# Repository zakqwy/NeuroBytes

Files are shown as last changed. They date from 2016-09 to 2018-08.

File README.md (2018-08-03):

## NOTE
This repository is no longer actively maintained or current. This clean break helped us do many things, such as:
- switch microcontroller platforms from ATtiny88 (8-bit AVR) to STM32L0s (ARM Cortex M0+)
- move from a single-board-fits-all strategy to specific boards that represent different types of biological elements
- change signaling from a simple 200ms pulse to a flexible mesh networking protocol
The new repositories can be found under the NeuroTinker GitHub account, found here: https://github.com/neurotinker.
# NeuroBytes
Official repo for NeuroBytes, an open-source hardware neuron simulator created by NeuroTinker, LLC. An exhuastive history of the project can be found at https://hackaday.io/project/3339-neurobytes, while more information on the company and people behind the project can be found at https://www.neurotinker.com. A good source for up-to-date and interesting pictures are the various NeuroTinker social media accounts: https://www.instagram.com/neurotinker, https://www.twitter.com/neurotinker, and https://www.facebook.com/neurotinker.
## Background
NeuroBytes were created to bridge the gap between middle- and high-school biology classes and postsecondary neuroscience education. We believe that a hands-on, modular, free-form tool in the spirit of LEGO, littleBits, or SnapCircuits that uniquely focuses on core neuroscience principles can connect engineering and biology concepts and ultimately improve STEM/STEAM retention rates for students as they pursue higher education. Our company's history goes back to 2012 and work done independently by Andrew Salveson (an architect) and Joe Burdo (a neuroscientist). After Zach Fredin created the first few generations of hardware simulators in 2014, Joe and Zach found each other via Hackaday.io and decided to collaborate on the project. In 2016, we were awarded a Phase I SBIR grant from the National Science Foundation and continue to work full-time on the project. NeuroBytes are not yet available for commercial sale, but we have sold a number of prototype kits to educators and students at a wide variety of levels and are always interested in collaborations. The project's creators can be easily reached via email: joe[at]neurotinker[dot]com and zach[at]neurotinker[dot]com.
## Hardware
All hardware files can be found under the /HARDWARE folder in this repository. The NeuroBytes boards, currently in version 0.91, were designed in KiCad v4.x. Various custom schematic symbols and PCB footprints were used, which are included in ZF.lib. The board outline itself along with the copper layer NeuroTinker logo were modified and redied for KiCad use using Inkscape and Gimp; various files titled v091-logo.xxx and v091_outline.xxx are included in the repo and were used in this process. Note that the NeuroTinker logo is a registered trademark of NeuroTinker, LLC and cannot be used without explicit permission from the company. Having said that, we urge interested parties to build and commercially sell electronic neuron simulators and accessories based on the NeuroBytes platform, keeping in mind the requirements outlined under our chosen license (GPLv3).
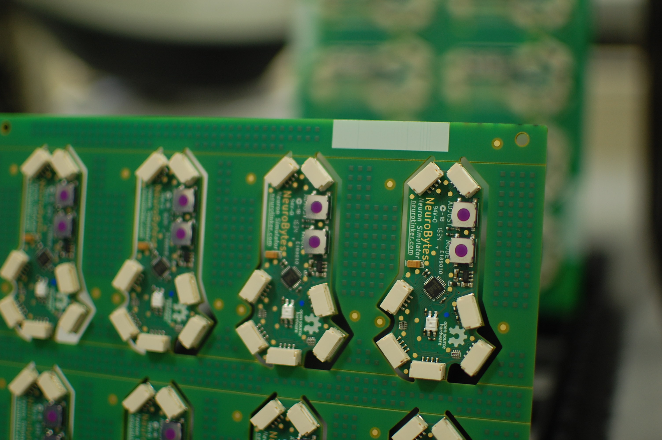
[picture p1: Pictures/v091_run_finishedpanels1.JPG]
v091_panel NeuroBytes v0.91 boards, fresh of the SMT line, 9/9/2016

## Firmware
All firmware files can be found under the /FIRMWARE folder in this repository. NeuroBytes (at least v0.91) are based around the ATtiny88 platform and programmed in AVR-C using the avrdude/gcc toolchain and an Adafruit USBtinyISP programmer. Each runtime program is standalone in its folder, including a suitable Makefile that configures the proper microcontroller fuses. As expected, the test_LED program just lights the RGB LED white to test a few connections; the v091_run-iaf (stands for "integrate-and-fire") folder holds the latest firmware iteration, and includes an operating mode for direct servo control (hold the 'mode' switch down for a few seconds to change this). As with any pre-commercial work-in-progress, the firmware will be changing rapidly but any code in this repo has been thoroughly tested (so let us know if it doesn't work).

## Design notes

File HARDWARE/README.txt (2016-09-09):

Copyright 2016 by Zach Fredin, NeuroTinker LLC
5/15/2016

NeuroBytes v0.9 is the ninth hardware iteration of the NeuroBytes project, a product designed and manufactured by NeuroTinker, LLC. The project is released under the terms of the GNU General Public License version 3 (LICENSE.txt). These boards are still to be considered prototypes, and as such may have bugs and mistakes that have not yet been recognized or fixed.

Changes vs NeuroBytes v0.8:

- Added on-board potentiometer
- Both axon signals now route to hardware PWM-capable pins
- Added on-board LDO and associated capacitors
- Added Schottky diode on microcontroller voltage rail
- Added OSHW logo to silkscreen
- Reduced LED hole size slightly
- Added pogo pads for testing axons, dendrites, etc.
- Changed MODE switch to standard type (vs right-angle)
- General silkscreen improvements/simplifications

Note that the PCB design file includes three copies of the board, along with a pogo rig breakout and a few accessory boards.

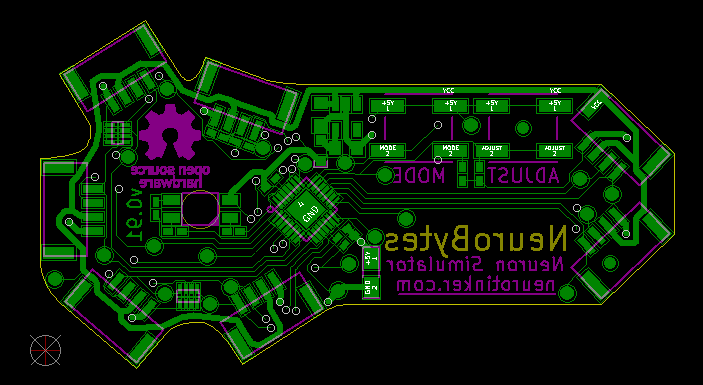
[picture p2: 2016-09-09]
HARDWARE/v091_PCBback.png

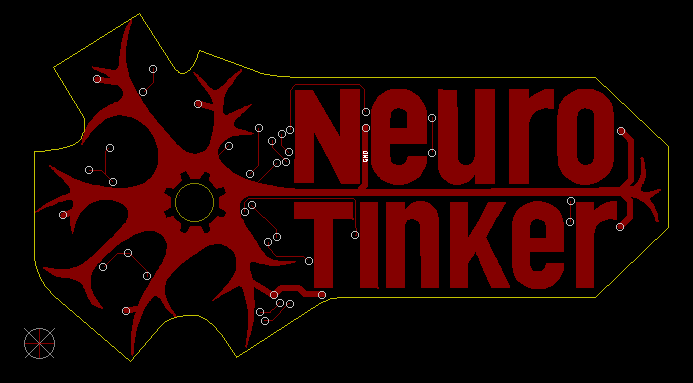
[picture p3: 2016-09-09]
HARDWARE/v091_PCBfront.png

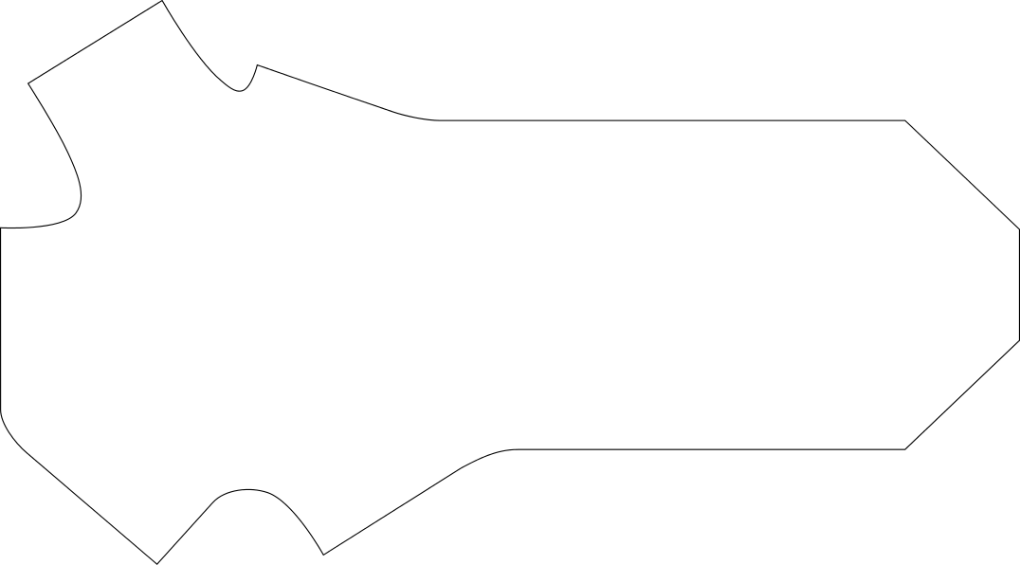
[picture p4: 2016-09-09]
HARDWARE/v091_outline.png

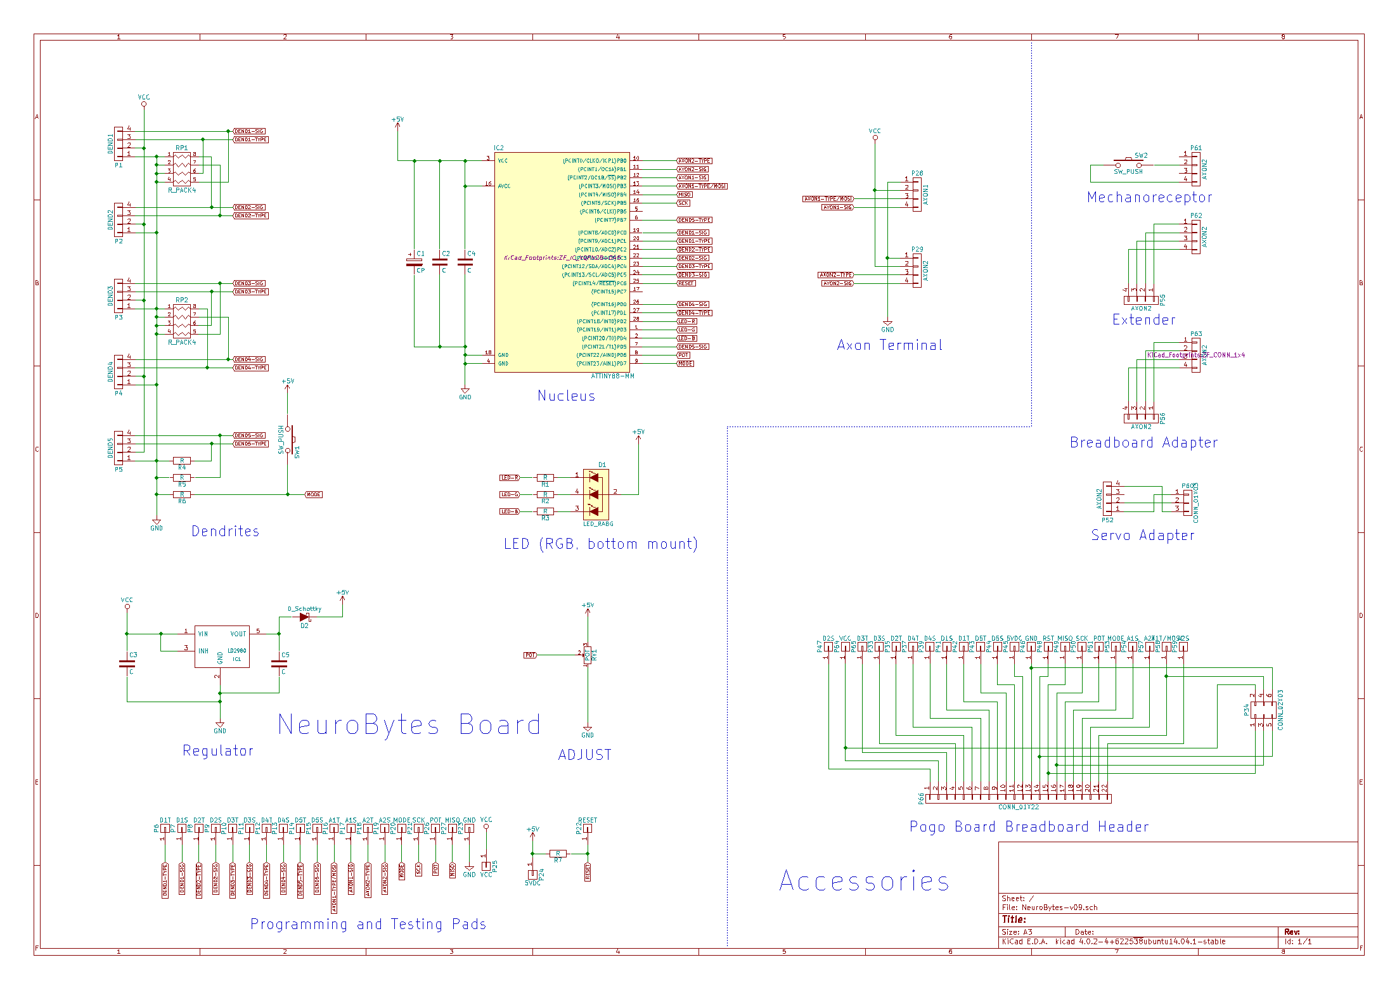
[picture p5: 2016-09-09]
HARDWARE/v091_schematic.png

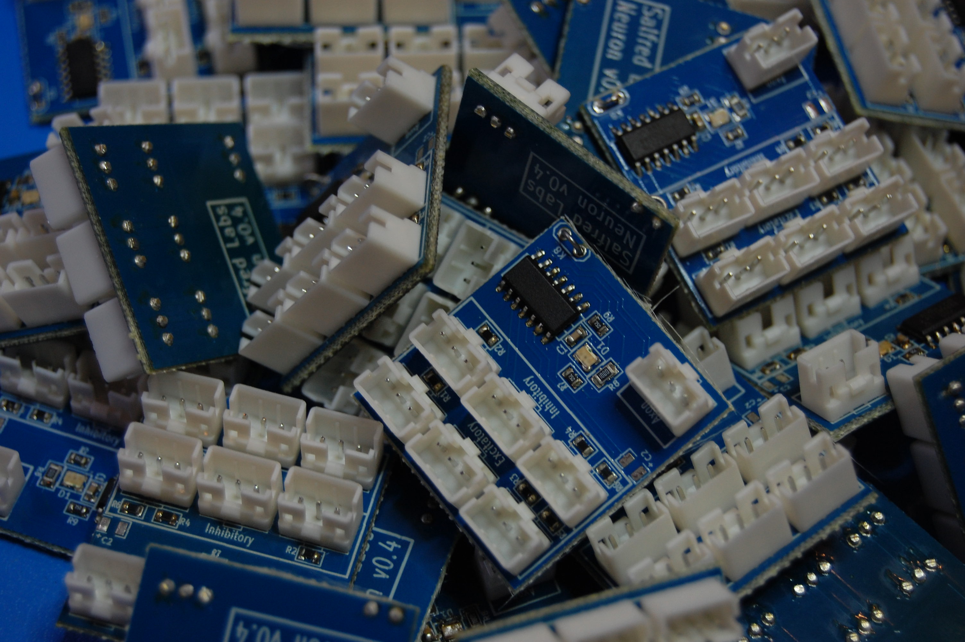
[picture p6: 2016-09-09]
Pictures/v04_pile.JPG

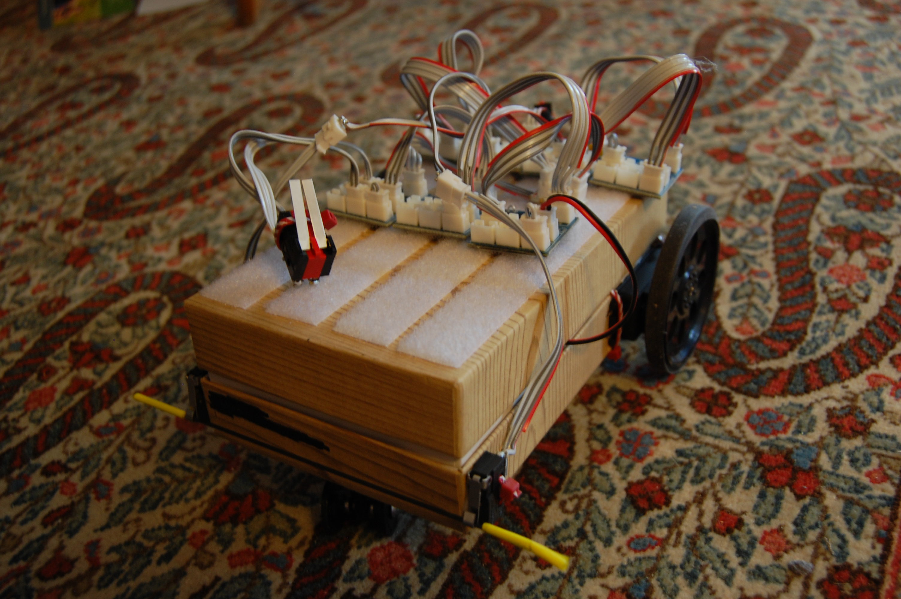
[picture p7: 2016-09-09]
Pictures/NeuroBuggy.JPG

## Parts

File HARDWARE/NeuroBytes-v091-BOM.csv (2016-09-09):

Title
Revision
Date
Generated | Thu 16 Jun 2016 06:22:55 PM CDT
Company
Comment 1
Comment 2
Comment 3
Comment 4
Total Parts | 50
Total Unique Parts | 15
Ref | Qty | Value | Link | Mfr | Mfr Part # | Package | RoHS | Subs Allowed
C4 C2 | 2 | 100 nF | https://www.digikey.com/product-detail/en/taiyo-yuden/LMK105BJ104KV-F/587-1227-2-ND/930579 | Taiyo Yuden | LMK105BJ104KV-F | 0402 | Yes | Yes
C3 | 1 | 1 uF | https://www.digikey.com/product-detail/en/taiyo-yuden/LMK107B7105KA-T/587-1242-2-ND/930594 | Taiyo Yuden | LMK107B7105KA-T | 0603 | Yes | Yes
C5 | 1 | 2.2 uF | https://www.digikey.com/product-detail/en/taiyo-yuden/LMK107BJ225KA-T/587-1253-2-ND/930605 | Taiyo Yuden | LMK107BJ225KA-T | 0603 | Yes | Yes
C1 | 1 | 10 uF | https://www.digikey.com/product-detail/en/kemet/T491A106K010AT/399-3684-2-ND/818545 | Kemet | T491A106K010AT | 1206 | Yes | Yes
D1 | 1 | RGB LED CA | https://www.digikey.com/product-detail/en/sunled/XZMDKCBDDG45S-9/1497-1257-1-ND/5169746 | SunLED | XZMDKCBDDG45S-9 | 4-PLCC bottom mtg | Yes | No
D2 | 1 | D_Schottky | https://www.digikey.com/product-detail/en/panasonic-electronic-components/DB2S30800L/DB2S30800LTR-ND/2325946 | Panasonic Electric Components | DB2S30800L | SC-79 | Yes | Yes
IC2 | 1 | ATTINY88-MM | https://www.digikey.com/product-search/en?keywords=ATTINY88-MMHR-ND | Atmel | ATTINY88-MMHR | 28-VQFN (4x4) | Yes | No
IC1 | 1 | LD2980ABM50TR | https://www.digikey.com/product-detail/en/stmicroelectronics/LD2980ABM50TR/497-1518-2-ND/591619 | STMicroelectronics | LD2980ABM50TR | SOT-23-5 | Yes | No
P1 P2 P3 P4 P5 P28 P29 | 7 | JST GH 4-position | https://www.digikey.com/product-detail/en/jst-sales-america-inc/SM04B-GHS-TB(LF)(SN)-/455-1566-2-ND/807788 | JST | SM04B-GHS-TB(LF)(SN)- | JST GH | Yes | No
R1 | 1 | 150 | https://www.digikey.com/product-detail/en/yageo/RC0402FR-07150RL/311-150LRCT-ND/729490 | Yageo | RC0402FR-07150RL | 0402 | Yes | Yes
R2 R3 | 2 | 100 | https://www.digikey.com/product-detail/en/yageo/RC0402FR-07100RP/YAG1248CT-ND/4935363 | Yageo | RC0402FR-07100RP | 0402 | Yes | Yes
R4 R5 R6 R7 R8 | 5 | 10k | https://www.digikey.com/product-detail/en/yageo/RC0402FR-0710KL/311-10.0KLRTR-ND/726523 | Yageo | RC0402FR-0710KL | 0402 | Yes | Yes
RP1 RP2 | 2 | 10k (x4) | https://www.digikey.com/product-detail/en/cts-resistor-products/741C083103JP/741C083103JPCT-ND/1124652 | CTS Resistor Products | 741C083103JP | 0804 | Yes | Yes
SW1 SW2 | 2 | SW_PUSH | https://www.digikey.com/product-detail/en/c-k-components/KSEM31J-LFS/CKN10425TR-ND/3487184 | C&K Components | KSEM31J LFS | J Lead | Yes | No
TP24 TP21 TP22 TP23 TP6 TP7 TP8 TP9 TP10 TP11 TP12 TP13 TP14 TP15 TP16 TP17 TP18 TP19 TP25 TP20 TP26 TP27 | 22 | Test Point
BOM made with KICAD_BOM_WIZARD (https://github.com/HashDefineElectronics/KiCad_BOM_Wizard.git)
Generated Thu 16 Jun 2016 06:22:55 PM CDT

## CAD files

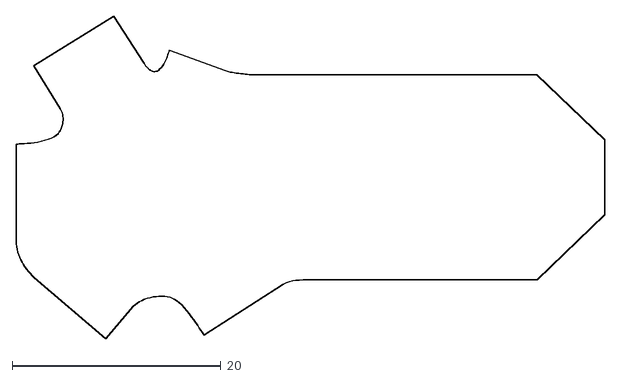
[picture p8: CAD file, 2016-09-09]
HARDWARE/v091_outline.dxf
56.4 x 30.9

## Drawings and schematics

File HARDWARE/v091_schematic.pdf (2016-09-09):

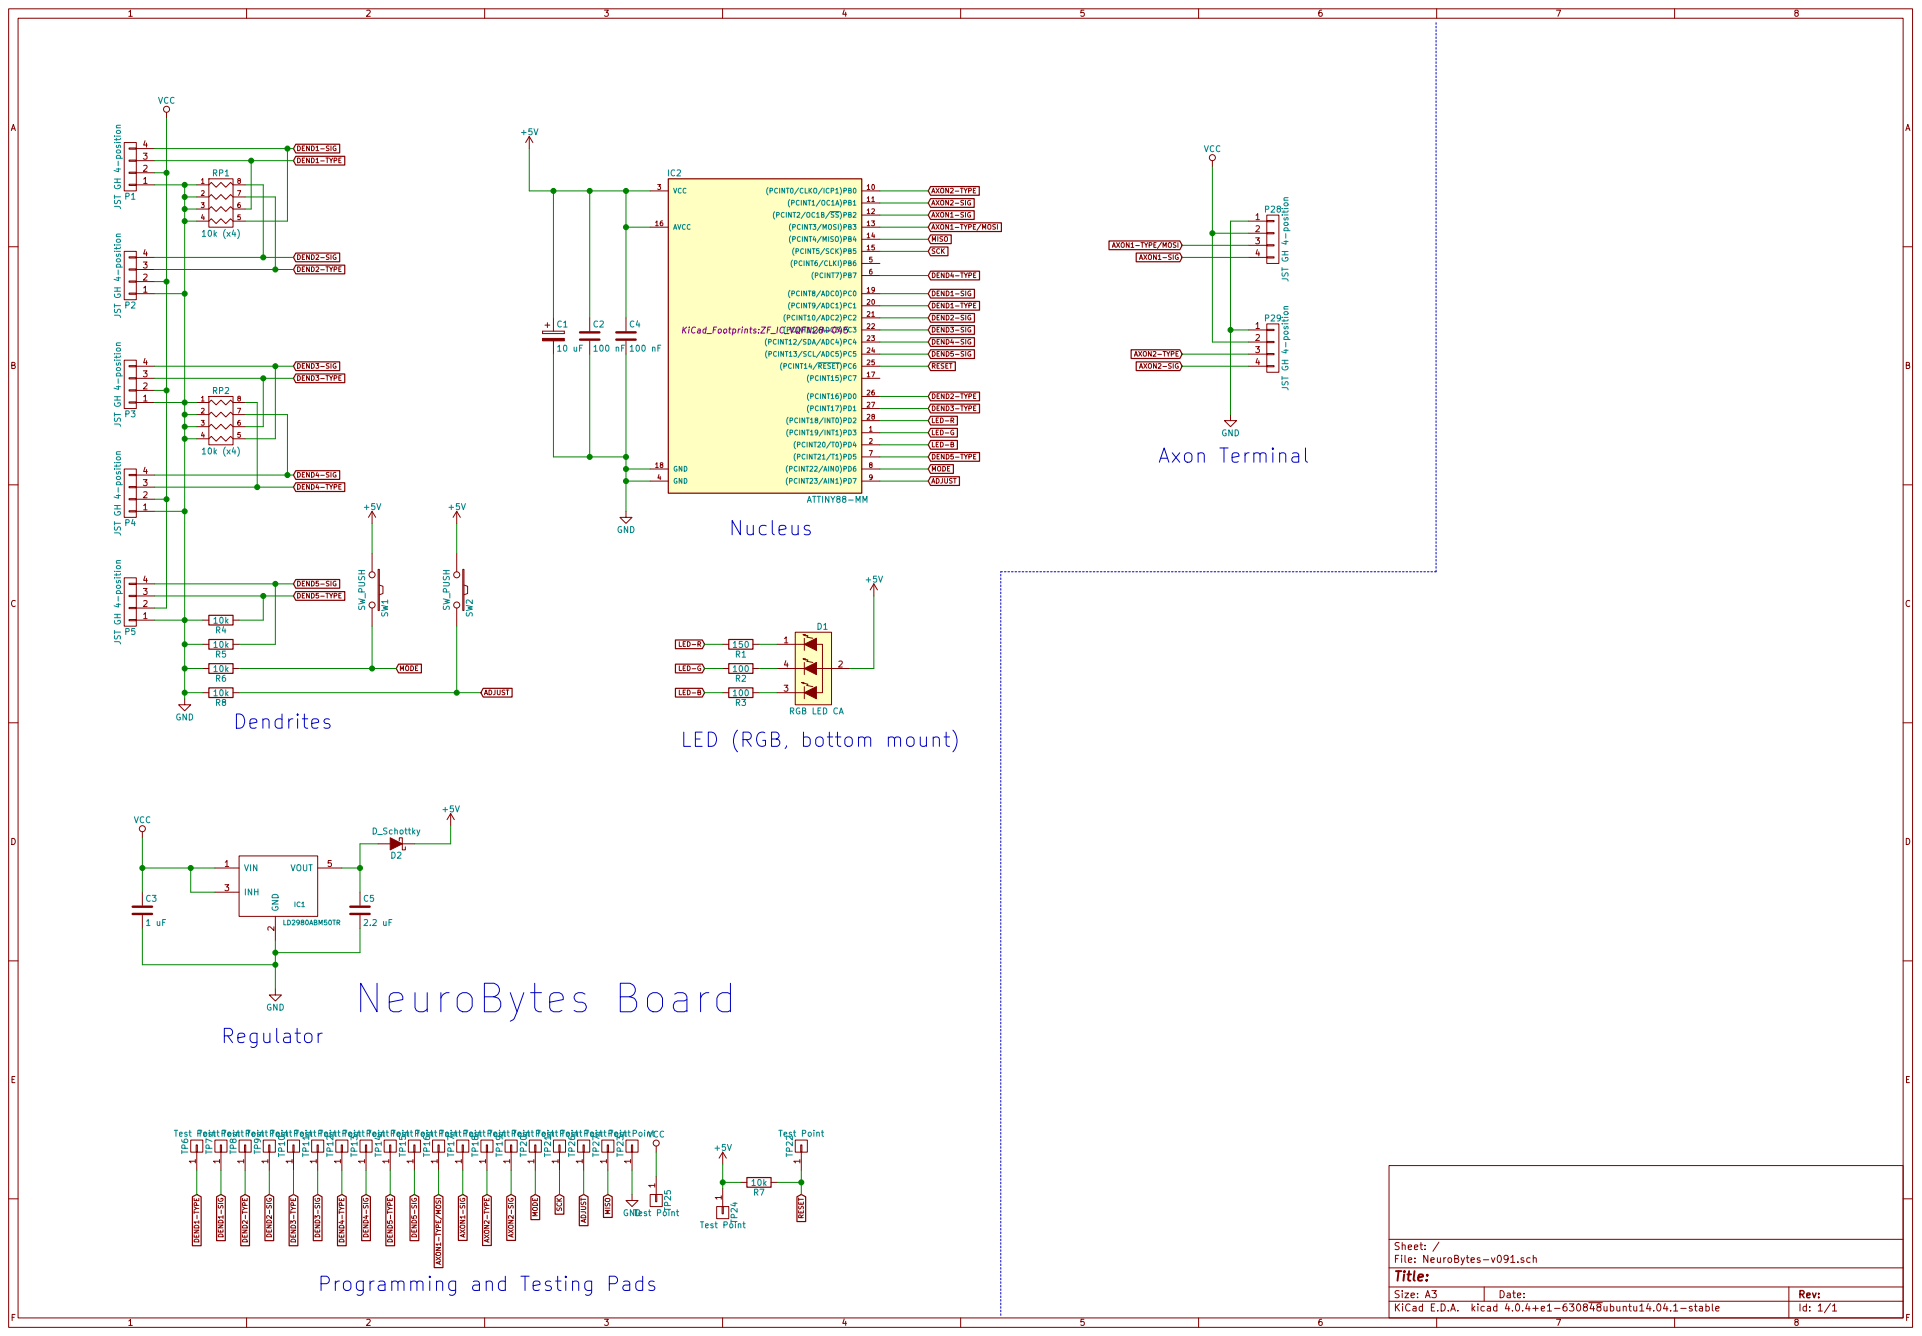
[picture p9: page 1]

4 P29 JST GH 4-position GND

LED (RGB, bottom mount)

1 TP6 Test Point 1 TP7 Test Point 1 TP8 Test Point 1 TP9 Test Point 1 TP10Test Point 1 TP11Test Point 1 TP12Test Point 1 TP13Test Point 1 TP14Test Point 1 TP15Test Point 1 TP16Test Point 1 TP17Test Point 1 TP18Test Point 1 TP19Test Point 1 TP25 Test Point 1 TP20Test Point

File: NeuroBytes-v091.sch Sheet: /

Programming and Testing Pads

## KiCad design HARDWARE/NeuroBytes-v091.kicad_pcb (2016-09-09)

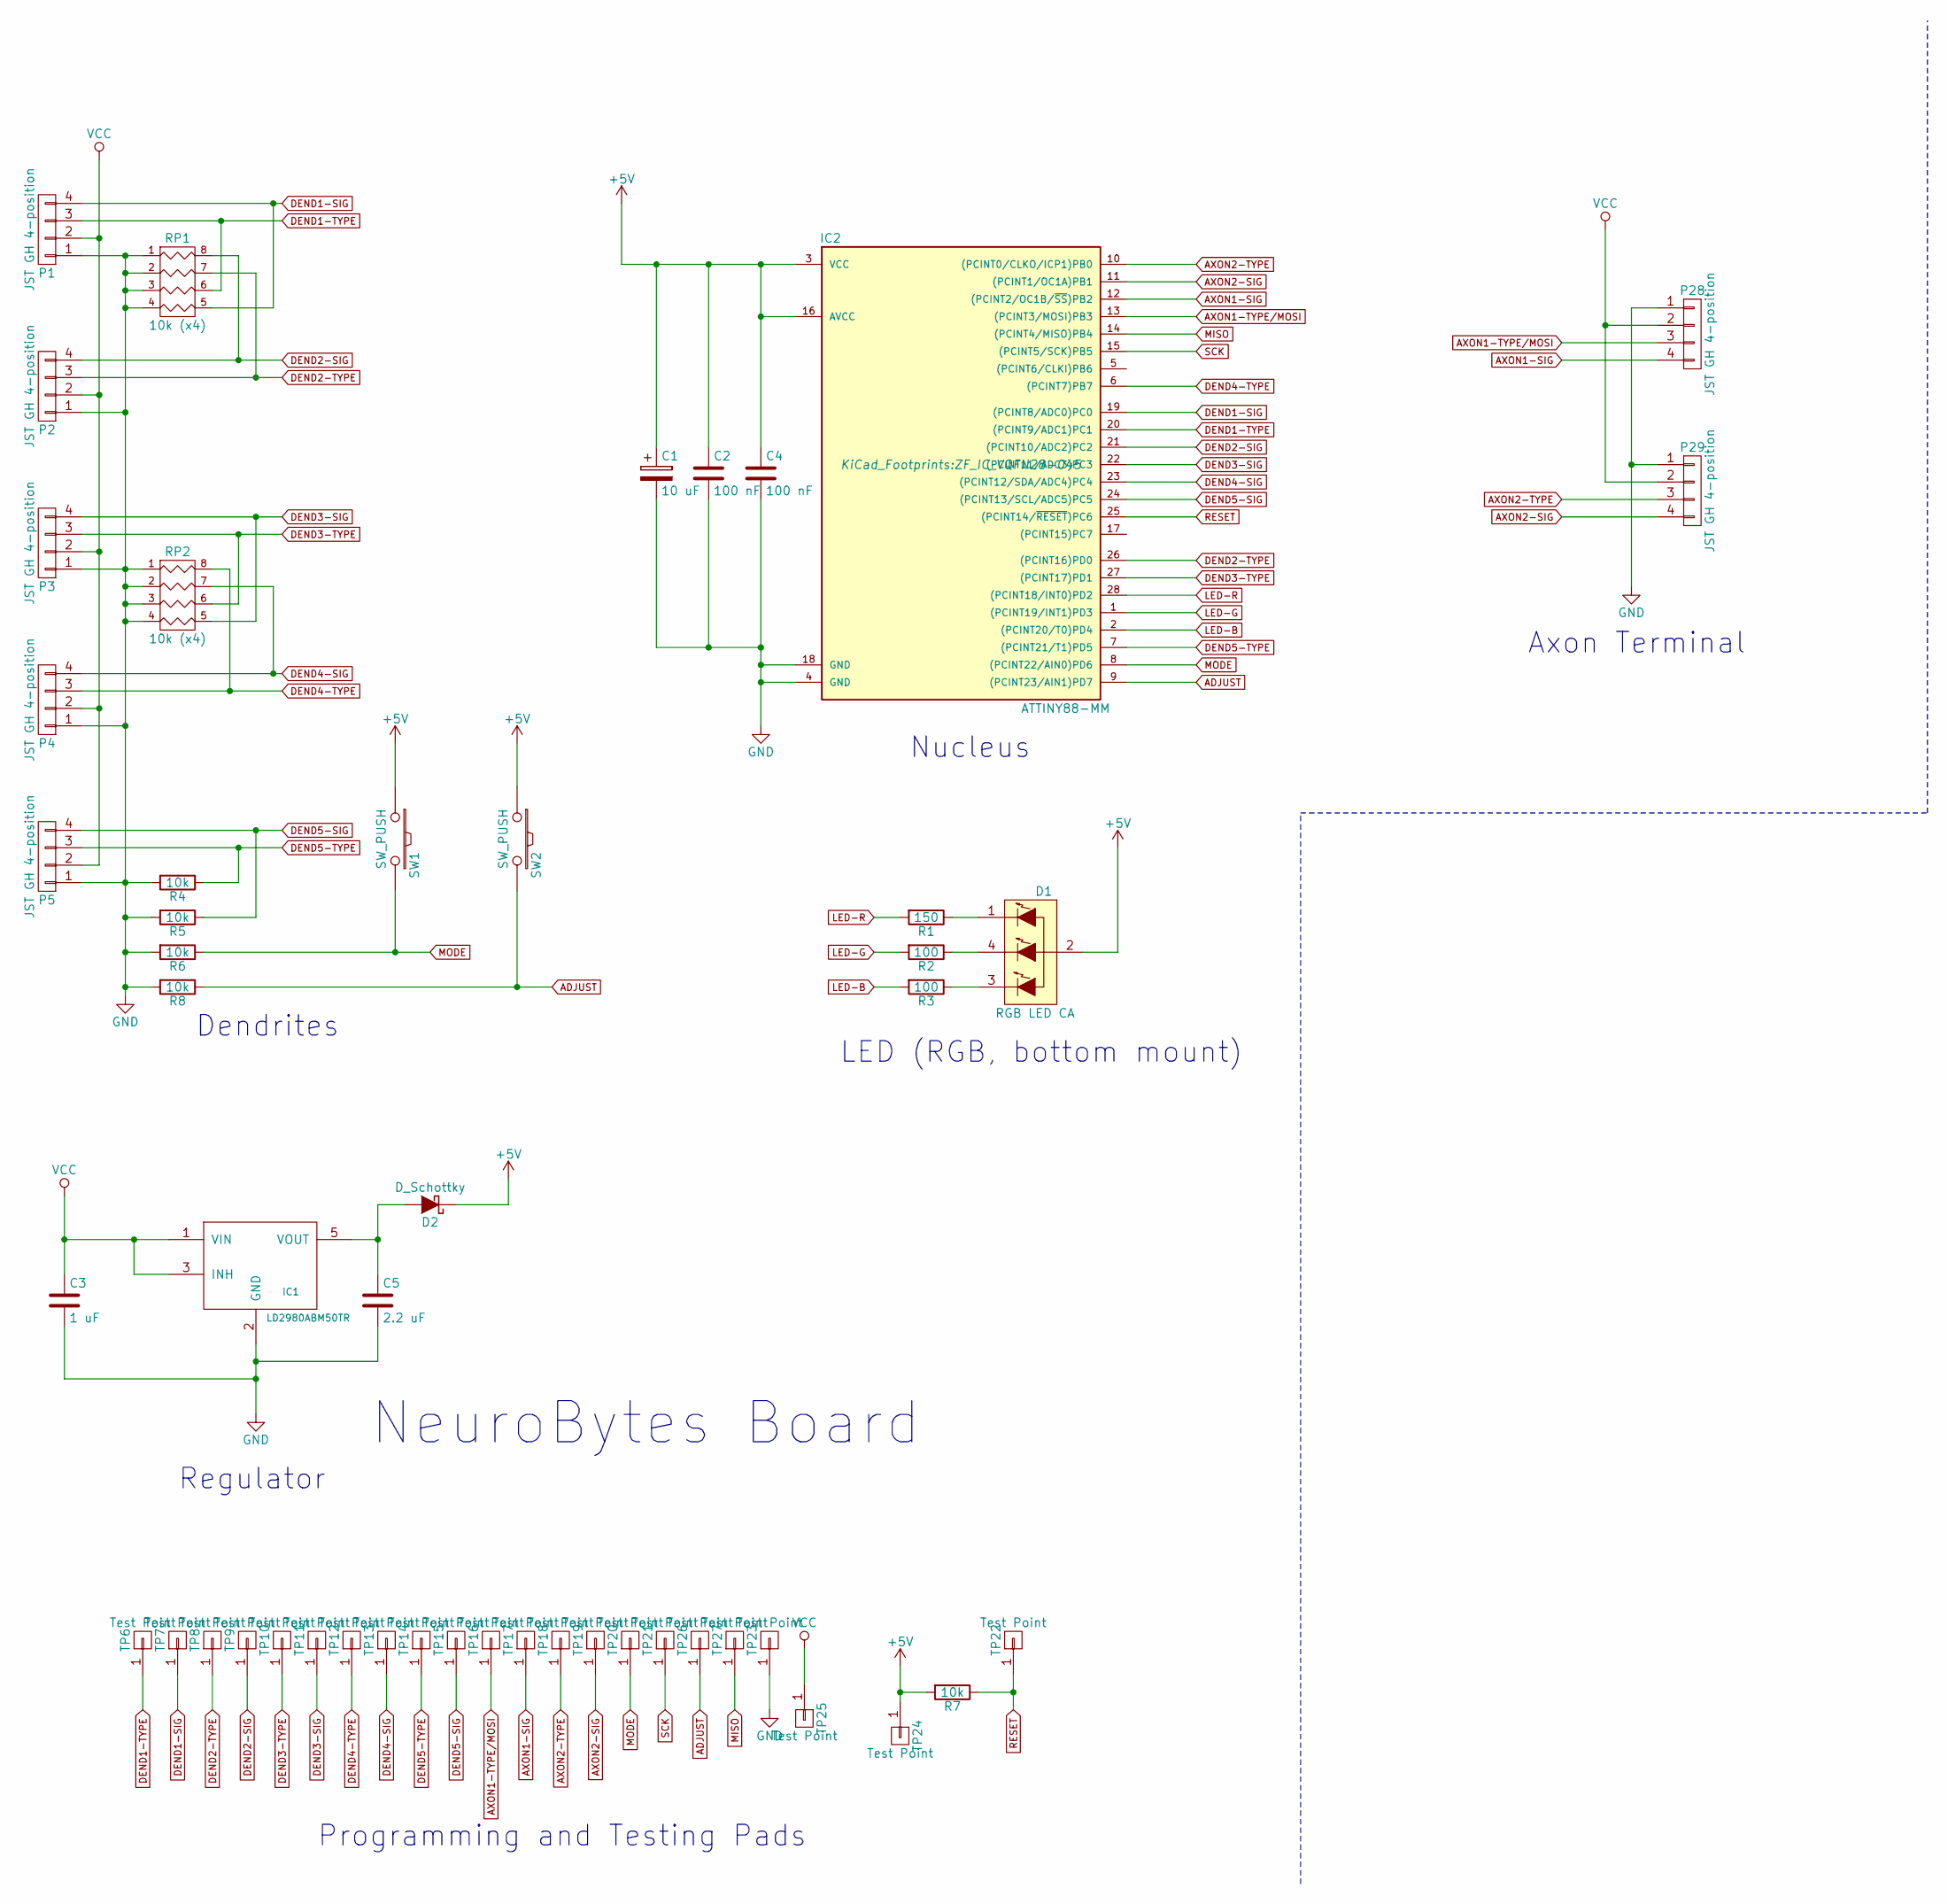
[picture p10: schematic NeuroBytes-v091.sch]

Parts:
C1: 10 uF; ZF_SMD_pol_1206; Mfr Part # T491A106K010AT
C2, C4: 100 nF; ZF_SMD_NonPol_0402; Mfr Part # LMK105BJ104KV-F
C3: 1 uF; ZF_SMD_NonPol_0603; Mfr Part # LMK107B7105KA-T
C5: 2.2 uF; ZF_SMD_NonPol_0603; Mfr Part # LMK107BJ225KA-T
D1: RGB LED CA; ZF_LED_RGB_SunLED_XZMDKCBDDG45S-9; Mfr Part # XZMDKCBDDG45S-9
D2: D_Schottky; ZF_SMD_pol_SC79; Mfr Part # DB2S30800L
IC1: LD2980ABM50TR; ZF_SOT23-5L; Mfr Part # LD2980ABM50TR
IC2: ATTINY88-MM; ZF_IC_VQFN28-045; Mfr Part # ATTINY88-MMHR
P1, P2, P3, P4, P5, P28, P29: JST GH 4-position; ZF_CONN_JST_GH; Mfr Part # SM04B-GHS-TB(LF)(SN)-
R1: 150; ZF_SMD_NonPol_0402; Mfr Part # RC0402FR-07150RL
R2, R3: 100; ZF_SMD_NonPol_0402; Mfr Part # RC0402FR-07100RP
R4, R5, R6, R7, R8: 10k; ZF_SMD_NonPol_0402; Mfr Part # RC0402FR-0710KL
RP1, RP2: 10k (x4); ZF_RN_4iso_CTS-0804; Mfr Part # 741C083103JP
SW1, SW2: SW_PUSH; ZF_SW_Momentary_KSEM31J; Mfr Part # KSEM31J LFS
TP6, TP7, TP8, TP9, TP10, TP11, TP12, TP13, TP14, TP15, TP16, TP17, TP18, TP19, TP20, TP21, TP22, TP23, TP24, TP25, TP26, TP27: Test Point; ZF_CONN_1-2_pad

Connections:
+5V: C1.1, C2.1, C4.1, D1.2 (COMMON_ANODE), D2.1 (K), IC2.3 (VCC), IC2.16 (AVCC), R7.2, SW1.1, SW2.1, TP24.1
ADJUST: IC2.9 ((PCINT23/AIN1)PD7), R8.1, SW2.2, TP26.1
AXON1-SIG: IC2.12 ((PCINT2/OC1B/~SS~)PB2), P28.4, TP17.1
AXON1-TYPE/MOSI: IC2.13 ((PCINT3/MOSI)PB3), P28.3, TP16.1
AXON2-SIG: IC2.11 ((PCINT1/OC1A)PB1), P29.4, TP19.1
AXON2-TYPE: IC2.10 ((PCINT0/CLKO/ICP1)PB0), P29.3, TP18.1
DEND1-SIG: IC2.19 ((PCINT8/ADC0)PC0), P1.4, RP1.5 (R4), TP7.1
DEND1-TYPE: IC2.20 ((PCINT9/ADC1)PC1), P1.3, RP1.6 (R3), TP6.1
DEND2-SIG: IC2.21 ((PCINT10/ADC2)PC2), P2.4, RP1.8 (R1), TP9.1
DEND2-TYPE: IC2.26 ((PCINT16)PD0), P2.3, RP1.7 (R2), TP8.1
DEND3-SIG: IC2.22 ((PCINT11/ADC3)PC3), P3.4, RP2.5 (R4), TP11.1
DEND3-TYPE: IC2.27 ((PCINT17)PD1), P3.3, RP2.6 (R3), TP10.1
DEND4-SIG: IC2.23 ((PCINT12/SDA/ADC4)PC4), P4.4, RP2.7 (R2), TP13.1
DEND4-TYPE: IC2.6 ((PCINT7)PB7), P4.3, RP2.8 (R1), TP12.1
DEND5-SIG: IC2.24 ((PCINT13/SCL/ADC5)PC5), P5.4, R5.1, TP15.1
DEND5-TYPE: IC2.7 ((PCINT21/T1)PD5), P5.3, R4.1, TP14.1
GND: C1.2, C2.2, C3.2, C4.2, C5.2, IC1.2 (GND), IC2.4 (GND), IC2.18 (GND), P1.1, P2.1, P3.1, P4.1, P5.1, P28.1, P29.1, R4.2, R5.2, R6.2, R8.2, RP1.1, RP1.2, RP1.3, RP1.4, RP2.1, RP2.2, RP2.3, RP2.4, TP23.1
LED-B: IC2.2 ((PCINT20/T0)PD4), R3.2
LED-G: IC2.1 ((PCINT19/INT1)PD3), R2.2
LED-R: IC2.28 ((PCINT18/INT0)PD2), R1.2
MISO: IC2.14 ((PCINT4/MISO)PB4), TP27.1
MODE: IC2.8 ((PCINT22/AIN0)PD6), R6.1, SW1.2, TP20.1
unnamed: C5.1, D2.2 (A), IC1.5 (VOUT)
unnamed: D1.1 (RED_CATHODE), R1.1
unnamed: D1.3 (BLUE_CATHODE), R3.1
unnamed: D1.4 (GREEN_CATHODE), R2.1
RESET: IC2.25 ((PCINT14/~RESET~)PC6), R7.1, TP22.1
SCK: IC2.15 ((PCINT5/SCK)PB5), TP21.1
VCC: C3.1, IC1.1 (VIN), IC1.3 (INH), P1.2, P2.2, P3.2, P4.2, P5.2, P28.2, P29.2, TP25.1

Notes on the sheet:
Nucleus
Dendrites
Regulator
LED (RGB, bottom mount)
Axon Terminal
Programming and Testing Pads
NeuroBytes Board

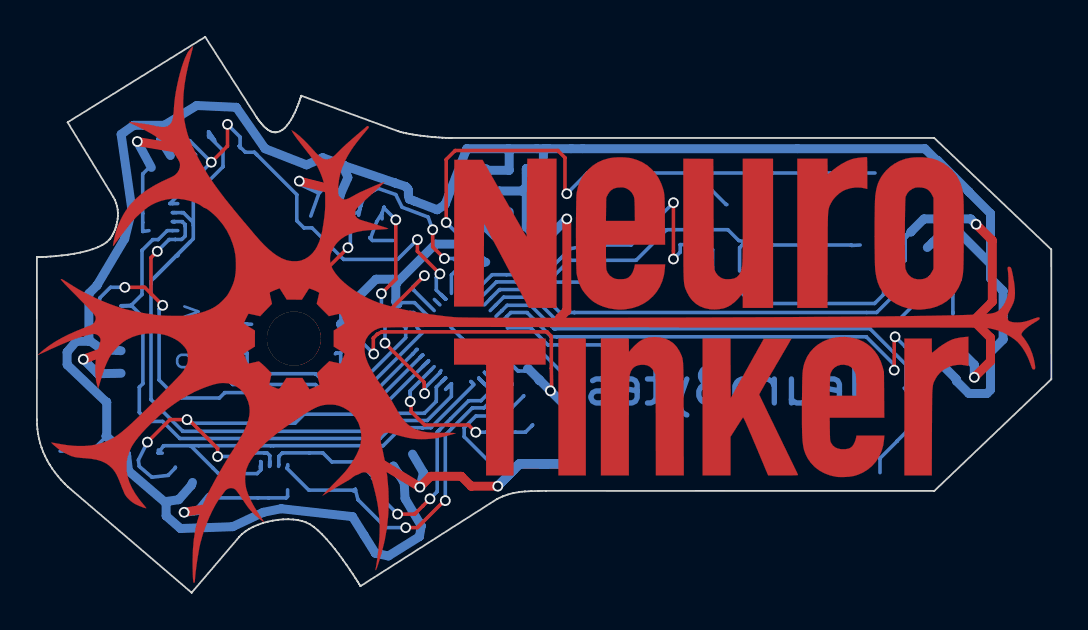
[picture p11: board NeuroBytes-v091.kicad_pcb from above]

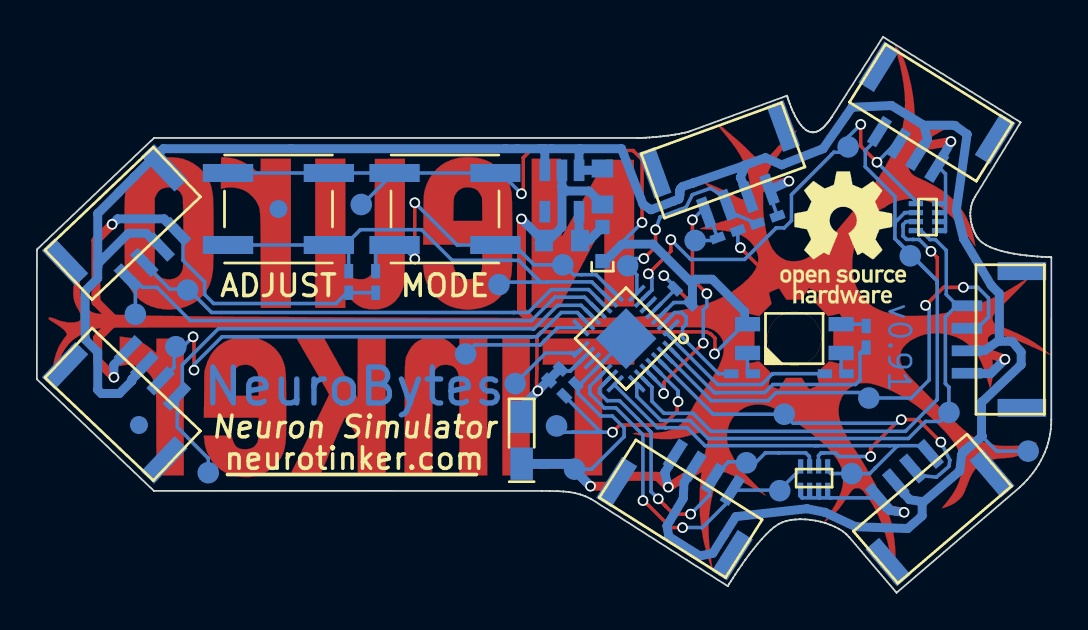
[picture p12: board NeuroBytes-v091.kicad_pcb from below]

Board: 2 copper layers, 56.4 x 30.9 mm, 50 parts (50 on the bottom side), 29 nets.

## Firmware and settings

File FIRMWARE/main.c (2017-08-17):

/*
    NeuroBytes v1.0 firmware

    Contributors:
    Zach Fredin
    Patrick Sullivan
    Jarod White

    1/7/2017
    
    
                    `.                                                                               
                   +                                                                                
                  .o                                                                                
               `-.+y               `                                                                
                `/yh.        .-  -:`                                                                
                   dm:        `sds         :++.  `++.  :+oo+-  -++` .++. -++-/+: -/+o+:            
               `/hmddd/        `d.`:.      /sso. .ss- +so::ss/ :ss` .ss- :sso/:.:ss/:oso            
              :s-`  `:yh.       dyo`       /ssss-.ss- ss/  +so :ss` .ss- :ss.   +so  :ss`           
             -:        /do`    -ys//-      /so:ss+ss- ssssssso :ss` .ss- :ss`   +so  :ss`           
                        dmdo--/do          /so :ssss- ss/  ``` :ss` .ss- :ss`   +so  :ss`           
         .             `hmNmhhmNh:`        /so  -sss- +so::ss/ :ss+:+ss- :ss`   :ss/:oso           
          -/o-.`     `:shhy..:`:hmds/:-`   :+/   -++.  :+++/-   :++/:++. -++`    -/+++:`         
         `-+hddhyhhhmmdmd/`+dmh-.smdso+++//:::::::::::::::::::::::::::////////////////////////:::   
       `-.` ys.   `/dmNdy: sNNh:`hNo       .%%%%%%..%%%%%%..%%..%%..%%..%%..%%%%%%..%%%%%..   
           .o      /hdddyso`-/`:syNm-      ...%%......%%....%%%.%%..%%.%%...%%......%%..%%.         
                 :hs/.``-hdhmNyhNmhdm+     ...%%......%%....%%.%%%..%%%%....%%%%....%%%%%..         
               -+:`      +shmy:` `+mhho`   ...%%......%%....%%..%%..%%.%%...%%......%%..%%.         
        .-..-oh/`       /dh/`      dm--//   ..%%....%%%%%%..%%..%%..%%..%%..%%%%%%..%%..%%.         
         -:/oho        od:        oNN:        -:.   .:- -:-  -:. -:.  .:- `-:::-`  ::`              
             `s`     `hss`      .:. ++                                                             
              `-     h: `/`         -+                                                              
                    :/              .:                                                              
                    +               .                                                               
                    -               
*/

#include <avr/io.h>
#include <avr/interrupt.h>
#include <avr/pgmspace.h>

#include "neuron.h"
#include "HAL.h"
#include "RGB_PWM.h"
//#include "bit_ops.h"
#include "states.h"

//#include <serial.h>

// Timing Macros
#define FIRE_RESET_TIME         200
#define AXON_PULSE_DELAY_TIME   100
#define AXON_PULSE_LENGTH       100
#define FIRE_LED_TIME           50
#define DECAY_TIME_RESET        6    //8

#define MODE_BUTTON_HOLD_TIME   500

int main(void)
{
	dendrite_magnitude_lookup[0] = 140;
	dendrite_magnitude_lookup[1] = 30;
	dendrite_magnitude_lookup[2] = 60;
	dendrite_magnitude_lookup[3] = 80;
	dendrite_magnitude_lookup[4] = 120;

    neuron_t neuron;

    uint16_t mode_button_count = 0;
	uint16_t adjust_button_count = 0;
	uint16_t decay_time = 0;
	uint16_t adbg = 0; // debug
	uint8_t	 led_breathing = 0;
	uint8_t	 breathing_count = 0;
	uint16_t	 flash_count = 0;
	uint16_t inhib_flag = 0;
	uint16_t last_fire_period = 0;
	volatile uint8_t n_var_v_delay_newest = 0;
	volatile uint8_t n_var_v_delay_oldest;
	volatile int16_t n_var_v_delay[10] = {0,0,0,0,0,0,0,0,0,0}; //delay buffer
	volatile uint8_t n_var_v_delay_mult;
	volatile uint8_t n_var_v_delay_mult_reset = 8;


    systemInit();
    setupTimer();

    neuronInit(&neuron);

	uint8_t i;

    for(;;){
		if (ms_tick != 0){
			ms_tick = 0;
			// check SPI for updated values
			/*
				SPI can:
				-change dendrite weightings and modes
				-change operating mode
				-change neuron parameters
			*/
			// send data to SPI
			// check mode button
			if (mode_button_pressed){
				mode_button_count++;
			} else{
				mode_button_count = 0;
			}

			if (adjust_button_pressed){
				adjust_button_count++;
			} else{
				adjust_button_count = 0;
			}
		
			if (mode_button_count == MODE_BUTTON_HOLD_TIME){
				changeMode(&neuron);
			}

			if (adjust_button_count == MODE_BUTTON_HOLD_TIME){
				changeHebb(&neuron);
			}
		
			//disableServo();
			switch(neuron.mode){
            
			case IAF:
				disableServo(); //debug
				// check dendrites
				checkDendrites(&neuron);
				// decay dendrites
				if (++decay_time > DECAY_TIME_RESET){
					decay_time = 0;
					dendriteDecayStep(neuron.dendrites);
					membraneDecayStep(&neuron);
				}
				switch(neuron.state){ // is the neuron integrating or firing?
            
					case INTEGRATE:
						
						// calculate new membrane potential and see if the neuron fires
						neuron.potential = neuron.fire_potential + calcNeuronPotential(&neuron);
						neuron.hebb_time++;
						if (neuron.potential >= MEMBRANE_THRESHOLD){
							neuron.state = FIRE;
							neuron.fire_time = 0;
							neuron.fire_potential = HYPERPOLARIZATION;
							for (i=0;i<5;i++){ // TODO: clear dendrites function
								neuron.dendrites[i].current_value = 0;
								neuron.dendrites[i].state = OFF;
								if (neuron.learning_state == HEBB){
									if (neuron.dendrites[i].timestamp < (neuron.hebb_time / 10)){
										neuron.dendrites[i].magnitude += (neuron.dendrites[i].magnitude * ((neuron.hebb_time / 10) - neuron.dendrites[i].timestamp) / (neuron.hebb_time / 10)) / 2;
										dendrite_magnitude_lookup[i] = neuron.dendrites[i].magnitude; // preserve dendritic weightings after switching hebb mode
									}
									if (neuron.dendrites[i].magnitude > 130){
										neuron.dendrites[i].magnitude = 130;
										dendrite_magnitude_lookup[i] = neuron.dendrites[i].magnitude;
									}
									neuron.dendrites[i].timestamp = 0;
								}
							}
							neuron.hebb_time = 0;

						}
						//translateColor(neuron.potential, IAF); // translate membrane potential to LED RGB values 
						if (neuron.potential == 0){
							if (neuron.learning_state == HEBB){
								if (++flash_count > 1000 && flash_count < 1100){
									translateColor(0, MOTOR);
								} else if (flash_count >= 1300 && flash_count < 1400){
									translateColor(0, MOTOR);
								} else if(flash_count >= 1400){
									flash_count = 0;
								}else{
									translateColor(neuron.potential, IAF);
								}
							} else{
							translateColor(neuron.potential, IAF);
							}
						}else{
						translateColor(neuron.potential, IAF);
						}
						
							/*
							if (++breathing_count > 4){
								//led_breathing = 0;
								if (led_breathing == 0){
									led_resolution++;
									if (led_resolution > 400){
										led_resolution = 400;
										led_breathing = 1;
									}
								} else if (led_breathing == 1){
									led_resolution--;
									if (led_resolution < 24){
										led_resolution = 24;
										led_breathing = 0;
									}
								}
								breathing_count = 0;
							}
							*/
						break;
                    
					case FIRE:
						neuron.fire_time++;
						neuron.potential = neuron.fire_potential + calcNeuronPotential(&neuron);
						if (neuron.fire_time > FIRE_RESET_TIME){ // neuron done firing
							neuron.state = INTEGRATE;
						} 
						else if (neuron.fire_time > AXON_PULSE_DELAY_TIME && neuron.fire_time - AXON_PULSE_DELAY_TIME < AXON_PULSE_LENGTH){
							// output pulse through axon after a delay
							setOutputPin(PIN_AXON_1);
							setOutputPin(PIN_AXON_2);
							PORTB |= ((1<<PB0) | (1<<PB1) | (1<<PB2) | (1<<PB3));
						} 
						else{
							clearOutputPin(PIN_AXON_1);
							clearOutputPin(PIN_AXON_2);
							PORTB &= ~((1<<PB0) | (1<<PB1) | (1<<PB2) | (1<<PB3));
						}

						if (neuron.fire_time < FIRE_LED_TIME){
							LEDfullWhite(); // make LED full white during fire time
						} else {
							translateColor(neuron.potential, IAF);
						}
						break;
				}
				break;

			case MOTOR:
				TCCR1A |= ((1<<COM1A1) | (1<<COM1B1)); //Fast PWM mode: clear OC1A/OC1B on Compare Match, set at TOP
				TCCR1A |= ((1<<WGM10) | (1<<WGM11)); //Fast PWM, 10-bit
				TCCR1B |= (1<<WGM12);
				TCCR1B |= (1<<CS12); //clk/256
				// calculate potential, buffer
				checkDendrites(&neuron);
				if (++decay_time > DECAY_TIME_RESET){
					decay_time = 0;
					dendriteDecayStep(neuron.dendrites);
					membraneDecayStep(&neuron);
				}

				neuron.potential = calcNeuronPotential(&neuron);
				inhib_flag = 0;
				for (i=0; i<5; i++){
					if (neuron.dendrites[i].type == INHIBITORY){
						inhib_flag = 1;
					}
				}
				if (inhib_flag == 0){
					if (n_var_v_delay_mult == n_var_v_delay_mult_reset) {
						n_var_v_delay_newest++;
						n_var_v_delay_mult = 0;
					}
					if (n_var_v_delay_newest > 9) {
						n_var_v_delay_newest = 0;
					}
					n_var_v_delay[n_var_v_delay_newest] = neuron.potential;

					n_var_v_delay_oldest = n_var_v_delay_newest + 1;
					if (n_var_v_delay_oldest > 9) {
						n_var_v_delay_oldest = 0;
					}
					neuron.potential = n_var_v_delay[n_var_v_delay_oldest];
					n_var_v_delay_mult++;
				}
            
				// axon PWM
				if (neuron.potential >= 120) {
					OCR1BL = 80;
					OCR1AL = 80;
				} else if (neuron.potential <= -120) {
					OCR1BL = 20;
					OCR1AL = 20;
				} else {
					OCR1BL =(neuron.potential / 4) + 50;
					OCR1AL =(neuron.potential / 4 ) + 50;
				}
				translateColor(neuron.potential, MOTOR);
				break;

			case IZHIK:
				disableServo(); //debug
				if (++decay_time > DECAY_TIME_RESET){
					decay_time = 0;
					membraneDecayStep(&neuron);
				}
				//translateColor(ADCH * neuron.scaling, IZHIK);
				translateColor(adbg, IZHIK);
				switch(neuron.state){
					case REST:
					
						if (--neuron.fire_period == 10){
							//neuron.fire_period = ADCH * neuron.scaling;
							adbg = ADCH;
							if (adbg == 0){
								changeADC(&neuron);
								if (neuron.analog_in_flag == 0){
									neuron.fire_period = 11;
								} else{
									neuron.fire_period = last_fire_period;
									neuron.state = FIRE;
									neuron.fire_time = 0;
									neuron.fire_potential = -50;
								}
							}else{
								neuron.analog_in_flag = 1;
								adbg = adbg * 6 + 30;
								neuron.fire_period = adbg;
								last_fire_period = neuron.fire_period;
								neuron.state = FIRE;
								neuron.fire_time = 0;
								neuron.fire_potential = -50;
							}
							//neuron.fire_period = 1000; //debug
							//neuron.potential = MEMBRANE_THRESHOLD;
						} else if (neuron.fire_period < 0){
							neuron.fire_period = ADCH * neuron.scaling;
						}
						neuron.potential = 0;
						//translateColor(neuron.potential, IZHIK); // translate membrane potential to LED RGB values
						break;
					
					case FIRE:
						neuron.fire_time++;
						neuron.potential = neuron.fire_potential;
						if (neuron.fire_time > FIRE_RESET_TIME){ // neuron done firing
							neuron.state = REST;
						}
						else if (neuron.fire_time > AXON_PULSE_DELAY_TIME && neuron.fire_time - AXON_PULSE_DELAY_TIME < AXON_PULSE_LENGTH){
							// output pulse through axon after a delay
							setOutputPin(PIN_AXON_1);
							setOutputPin(PIN_AXON_2);
						}
						else{
							clearOutputPin(PIN_AXON_1);
							clearOutputPin(PIN_AXON_2);
						}

						if (neuron.fire_time < FIRE_LED_TIME){
							LEDfullWhite(); // make LED full white during fire time
							} else {
							//translateColor(neuron.potential, IZHIK);
						}
						break;
				}
				break;
			}
			
		}
	}
}

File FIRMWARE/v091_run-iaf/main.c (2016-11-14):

/*
	NeuroBytes v091 run program
	v091_run-iaf/main.c
	Integrate-and-fire runtime program similar to that implemented in v04.	
	Zach Fredin
	6/11/2016
*/

#include <avr/io.h>
#include <avr/interrupt.h>
#include <avr/pgmspace.h>

/*
	FRONT VIEW (connectors on BACK):
	   _
 	_-- \
	\ D4 \_----______________________
	 \      D5     MODE    ADJUST    \
	 _\                            A2 \
	|                NEURO            |
	| D3     LED    TINKER            |
	|                              A1 /
	 \ D2  _ D1 _____________________/
	  \  _-	----   
	   \-

	DEND1-SIG	PC0/ADC0	DEND1-TYPE	PC1
	DEND2-SIG	PC2/ADC2	DEND2-TYPE	PD0
	DEND3-SIG	PC3/ADC3	DEND3-TYPE	PD1
	DEND4-SIG	PC4/ADC4	DEND4-TYPE	PB7
	DEND5-SIG	PC5/ADC5	DEND5-TYPE	PD5

	AXON1-SIG	PB2/OC1B	AXON1-TYPE	PB3
	AXON2-SIG	PB1/OC1A	AXON2-TYPE	PB0

	LED-R		PD2
	LED-G		PD3
	LED-B		PD4

	MODE		PD6
	ADJUST		PD7
*/

/* neuron variables */
volatile uint16_t n_var_v; //current membrane potential value
volatile uint16_t n_var_v_temp; //temp used to stage calculation
const uint16_t n_con_v_rest = 32767; //membrane potential rest value, usually 32767
const uint16_t n_con_threshold = 32867; //action potential threshold value, usually 32867
volatile uint8_t n_var_mode = 0; //0 = IAF, 1 = motor
volatile uint16_t n_var_mode_count = 0;
const uint16_t n_con_mode_count_reset = 3000;
volatile uint8_t n_var_mode_armed = 1; 	
volatile uint8_t n_var_v_delay_newest;
volatile uint8_t n_var_v_delay_oldest;
volatile uint16_t n_var_v_delay[60]; //delay buffer
volatile uint8_t n_var_v_delay_mult;
volatile uint8_t n_var_v_delay_mult_reset = 8;

/* dendrite variables */
volatile uint8_t d_var_status[5]; //current and previous dendrite status, LSB = most recent value
volatile uint8_t d_var_type; //current type xxxTTTTT, where TTTTT represents the TYPE pins of the dendrites, LSB = DEND1, high = exc
volatile uint8_t d_var_selected; //selected dendrite (used for staging algorithm)
volatile uint16_t d_var_val[5]; //sensed membrane potential contribution +/- 32767
volatile uint16_t d_var_decay[5] = {32767,32767,32767,32767,32767}; //stored membrane potential decay contribution +/- 32767
const uint16_t d_con_mag_lookup[5] = {130,60,70,80,110}; //input magnitudes

/* LED variables */
volatile uint8_t l_var_val[3]; //current LED value, R/G/B, 0 to [LED_con_resolution]
volatile uint8_t l_var_tick = 0; //current LED tick, resets when equal to LED_con_resolution
const uint8_t l_con_resolution = 255; //LED fading resolution, flicker rate = 1 / (L_con_resolution * 0.00004) Hz

/* servo variables */
volatile uint16_t s_var_val = 0;
volatile uint16_t s_var_val_count = 48;
const uint16_t s_con_val_reset = 1000;

/* timing variables */
volatile uint8_t t_var_tick = 0; //ISR flips this to non-zero to update main loop every 40 us
volatile uint8_t t_var_timer = 0; //slow loop counter
volatile uint8_t t_var_timer_reset = 20; //slow counter reset in ticks
volatile uint8_t t_var_decay = 0;
volatile uint8_t t_var_decay_reset = 40;
volatile uint8_t t_var_fire = 50;
volatile uint8_t t_var_fire_reset = 50;
volatile uint16_t t_var_axon_delay = 0;
const uint16_t t_con_axon_delay_reset = 500;
volatile uint8_t t_var_axon_pulse = 0;
const uint8_t t_con_axon_pulse_reset = 50;

void getDendriteStatus(void) {
/*	implementation of Elliot Williams' debounce strategy. shifts previous dendrite status history and stores latest value
	in d_var_status[] LSB. */
	uint8_t dend;
	for (dend=0;dend<5;dend++) {
		d_var_status[dend] <<= 1;
	}
	d_var_status[0] |= (PINC & (1<<PC0));
	d_var_status[1] |= ((PINC & (1<<PC2)) >> 2);
	d_var_status[2] |= ((PINC & (1<<PC3)) >> 3);
	d_var_status[3] |= ((PINC & (1<<PC4)) >> 4);
	d_var_status[4] |= ((PINC & (1<<PC5)) >> 5);
}

void getDendriteType(void) {
// updates d_var_type to xxxTTTTT, where TTTTT represents the input _type_ of the five dendrites (LSB = DEND, exc = 0, inh = 1)
	uint8_t temp = d_var_type;
	if (n_var_v >= n_con_v_rest) {
		temp = 0;
	}
	temp |= ((PINC & (1<<PC1)) >> 1);
	temp |= ((PIND & (1<<PD0)) << 1);
	temp |= ((PIND & (1<<PD1)) << 1);
	temp |= ((PINB & (1<<PB7)) >> 4);
	temp |= ((PIND & (1<<PD5)) >> 1);
	d_var_type = temp;
}

void calcDend(uint8_t dend) {
/*	updates the dendrite value (d_var_val) and dendrite decay (d_var_dec) arrays based on input and history. 
	staged using [dend] argument. uses 16-bit integers so interrupts should be disabled prior to calling. */
	d_var_val[dend] = 32767;
	if (d_var_status[dend] & 0b00000111) {
		if (d_var_type & (1<<dend)) {
			d_var_val[dend] -= d_con_mag_lookup[dend];
		}
		else {
			d_var_val[dend] += d_con_mag_lookup[dend];
		}
	}
	if ((d_var_status[dend] & 0b11000111) == 0b11000000) {
		d_var_status[dend] = 0;
		if (d_var_type & (1<<dend)) {
			d_var_decay[dend] -= d_con_mag_lookup[dend];
		}
		else {
			d_var_decay[dend] += d_con_mag_lookup[dend];
		}
	}
}

void decayDend(uint8_t dend) {
/* decays d_var_dec by d_con_dec when called. staged with [dend]. checks input values to avoid overflows. 16 bit integers so 
disable interrupts prior to calling. */
	if (d_var_decay[dend] > 32767) {
		if (t_var_decay > t_var_decay_reset) {
			t_var_decay = 0;
			d_var_decay[dend] = 32767 + (((d_var_decay[dend] - 32767) * 63) >> 6);
			if (d_var_decay[dend] < 32767) {
				d_var_decay[dend] = 32767;
			}
		}
	}
	else if (d_var_decay[dend] < 32767) {
		if (t_var_decay > t_var_decay_reset) {
			t_var_decay = 0;
			d_var_decay[dend] = 32767 - (((32767 - d_var_decay[dend]) * 63) >> 6); 
			if (d_var_decay[dend] > 32767) {
				d_var_decay[dend] = 32767;
			}
		}
	}	

	t_var_decay++;
}

void calcV(uint8_t dend) {
/* 	updates v with fresh d_var_val and d_var_dec values. 16 bit integers so disable interrupts prior to calling.
	staged to control execution time. */
	if (dend == 0) {
		n_var_v_temp = n_con_v_rest;
	}

	if (d_var_val[dend] >= 32767) {
		n_var_v_temp += (d_var_val[dend] - 32767);
	}
	else {
		n_var_v_temp -= (32767 - d_var_val[dend]);
	}

	if (d_var_decay[dend] >= 32767) {
		n_var_v_temp += (d_var_decay[dend] - 32767);
	}
	else {
		n_var_v_temp -= (32767 - d_var_decay[dend]);
	}

	if (dend == 4) {
		n_var_v = n_var_v_temp;
	}

}

void bufferV(void) {
/*	used to introduce delays into v calculation, specifically for excitatory motor application (so inhibitory
	and excitatory pulses arrive simultaneously to opposing servos). delay time is based on buffer size, which
	is _severely_ limited by on-board SRAM! should only be called if no inputs are inhibitory. */
	if (n_var_v_delay_mult == n_var_v_delay_mult_reset) {
		n_var_v_delay_newest++;
		n_var_v_delay_mult = 0;
	}
	if (n_var_v_delay_newest > 59) {
		n_var_v_delay_newest = 0;
	}
	n_var_v_delay[n_var_v_delay_newest] = n_var_v;

	n_var_v_delay_oldest = n_var_v_delay_newest + 1;
	if (n_var_v_delay_oldest > 59) {
		n_var_v_delay_oldest = 0;
	}
	n_var_v = n_var_v_delay[n_var_v_delay_oldest];
	n_var_v_delay_mult++;
}
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

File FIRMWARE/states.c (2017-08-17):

/*

State machine for switching through operating modes and controlling parameters.

TODO: add changing pin modes to HAL and change pin modes during inits.

*/
#include <avr/io.h>
#include "HAL.h"
//#include <RGB_PWM.h>

 void changeMode(neuron_t *n)
 {
	switch(n->mode){
		case IAF:
			IZHIK_init(n);
			n->mode = IZHIK;
			break;
		case IZHIK:
			MOTOR_init(n);
			n->mode = MOTOR;
			break;
		case MOTOR:
			n->mode = IAF;
			IAF_init(n);
			break;
	}
 }

 void IAF_init(neuron_t *n)
 {
	uint8_t i;

	disableServo();

	n->potential = 0;
	n->mode = IAF;
	n->state = INTEGRATE;

	n->fire_time = 0;

	for (i=0;i<DENDRITE_COUNT;i++){
		n->dendrites[i].state = OFF;
		n->dendrites[i].history = 0b00000000;
		n->dendrites[i].current_value = 0;
		n->dendrites[i].mode = DIGITAL;
		n->dendrites[i].type = EXCITATORY;
	}
 }

 void MOTOR_init(neuron_t *n)
 {
	enableServo();
	TCCR1A |= ((1<<COM1A1) | (1<<COM1B1)); //Fast PWM mode: clear OC1A/OC1B on Compare Match, set at TOP
	TCCR1A |= ((1<<WGM10) | (1<<WGM11)); //Fast PWM, 10-bit
	TCCR1B |= (1<<WGM12);
	TCCR1B |= (1<<CS12); //clk/256

	n->potential = 0;
	n->mode = MOTOR;
 }

 void IZHIK_init(neuron_t *n)
 {
	uint8_t i;
	disableServo();
	 /* set up ADC */
	 
	 PRR &= ~(1<<PRADC); //ensures power reduction bit is cleared
	 ADCSRA |= (1<<ADEN); //enables the ADC
	 ADCSRA |= (1<<ADSC); //start running ADC conversion (in free-running mode by default)
	 ADCSRA |= ((1<<ADPS2) | (1<<ADPS1)); //prescales ADC clock to clk/64 (125 kHz)
	ADCSRA |= (1<<ADATE); // set conversion auto-triggering
	 ADMUX |= (1<<ADLAR); //left adjusts ADC result
	 ADMUX |= (1<<REFS0); //ensures ADC references AVcc
	 //note: MUX[3:0] set to 0000 by default which selects AIN0
	 ADMUX = 0b01100000; // select ADC 0 => dendrite 0 excitatory

	 n->analog_in_flag = 0;

	ADCSRB &= 11111000; // set free-running mode
	n->fire_period	= 11;
	n->mode = IZHIK;
	n->scaling = 1;
	n->state = REST;
 }

 void changeHebb(neuron_t *n)
 {
	if (n->learning_state == NONE){
		translateColor(0, MOTOR);
		n->learning_state = HEBB;
		HEBB_init(n);
	} else{
		n->learning_state = NONE;
		neuronInit(n);
		//led_resolution = 156;
	}
 }

 void changeADC(neuron_t *n)
 {
		 //ADMUX = 0b01100000; // select ADC 0 => dendrite 0 excitatory
		 //ADMUX = 0b01100010; // select ADC 2 => dendrite 1 excitatory
		 //ADMUX = 0b01100011; // select ADC 3 => dendrite 2 excitatory
		 //ADMUX = 0b01100100; // select ADC 4 => dendrite 3 excitatory
		 //ADMUX = 0b01100101; // select ADC 5 => dendrite 4 excitatory
	switch(ADMUX){

		case 0b01100000:
			ADMUX = 0b1100010;
			break;

		case 0b01100010:
			ADMUX = 0b01100011;
			break;

		case 0b01100011:
			ADMUX = 0b01100100;
			break;

		case 0b01100100:
			ADMUX = 0b01100101;
			break;

		case 0b01100101:
			ADMUX = 0b01100000;
			break;
	}
 }

 void HEBB_init(neuron_t *n)
 {
	n->hebb_time = 0;
 }

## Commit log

2016-09-09 added PCB and schematic screenshots
    [NeuroBytes-v091.kicad_pcb]
2016-11-14 Updated getDendriteType() for compatibility with switches that only hold the TYPE line high when actuated.
